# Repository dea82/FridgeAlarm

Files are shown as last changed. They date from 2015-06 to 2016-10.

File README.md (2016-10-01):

# FridgeAlarm

## System overview
Alarm system for unintentionally open fridge door

## Requirements

## Design
### Component selection

### Box design

### PCB

### Software
[Doxygen documentation](http://dea82.github.io/FridgeAlarm)

#### Doxygen deployment by Travis
The source code documentation is generated with [Doxygen](http://www.doxygen.com) and pushed automatically to GitHub Pages by [Travis CI](http://www.travis-ci.org).

##### Setup
This assumes that you've already figures out how to genereate Doxygen documentation and are able to build with Travis CI.

To be able to automatically update Doxygen documentation when a commit is done to GitHub follow these steps:
###### Generation of SSH-key
1. Generate a new SSH key with the following command: 
`ssh-keygen -t rsa -b 4096 -C "your_email@example.com"`
2. You are then prompted to enter a name for the new keypair. Enter a file in which to save the key.
3. When asked for passphrase just press ENTER for empty passphrase. Confirm with ENTER again.

###### Setup GitHub
1. Navigate to your GitHub settings page `https://github.com/<username>/<your_repository>/settings/keys` and paste the content from the public ssh-key file, the one ending with .pub. **Make sure to check the box that allows write access!**

###### Setup Travis CI
This is the trickiest part.
1. Make sure you're able to connect to Travis console.
2. Run command: `travis encrypt-file name-of-key-generated`.
It's the key that doesn't end with .pub that shall be used.
3. You get an instruction from Travis CI. As it says you should now make sure to add the returned key, ending with .enc, to your repository. All others keys can and should now be removed!
4. Next update your .travis.yml with the encryption label, the 12-digit hex value returned from step 2.
```
env:
	global:
    	- ENCRYPTION_LABEL: "12-digit hex value"
```
TODO: Finalize
https://gist.github.com/domenic/ec8b0fc8ab45f39403dd

## Verification

### Install
To upload the hex-file to the MCU (Attiny85) I use the following command with avrdude:
`avrdude -B250 -cusbasp -pt85 -Uflash:w:<path to hex file> -Ulfuse:w:0xE2:m -Uhfuse:w:0x55:m`
The -B250 makes it slow - however if the clock of the MCU is to slow it might not work otherwise.

#### Fuses
|MCU |Low fuse|High fuse|
|---|:---:|:---:|
|Attiny13A|0x7A |0xFA |
|Attiny85 |0xE2 |0x55 |
### Power consumption
The following current consumption has been observed with prototype pcb, Attiny85 and magnetic buzzer.
System mode      |Current consumption [mA]
-----------------|:-----------------------:
Buzzer and LED ON|42
LED ON			 |2.3
Deep sleep		 |0.024

The following current consumption has been observed with production pcb, Attiny13A and piezo buzzer.
System mode      |Current consumption [mA]
-----------------|:-----------------------:
Buzzer and LED ON|5
LED ON			 |2.2
Deep sleep		 |0.024

## Conclusion

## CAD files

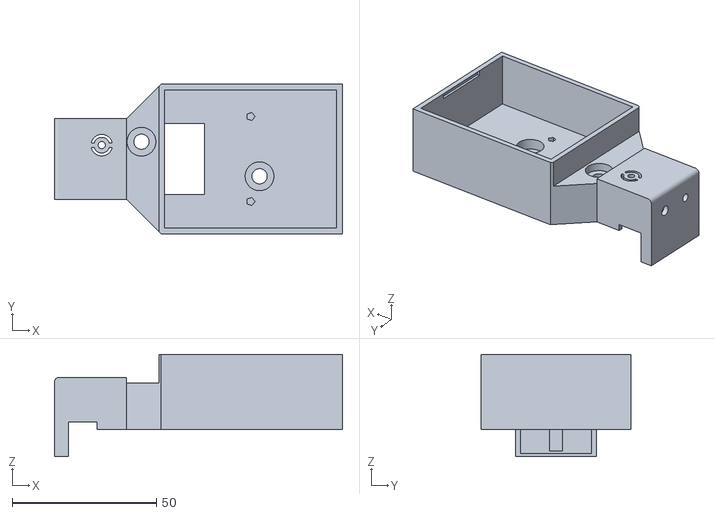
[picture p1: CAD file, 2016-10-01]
cad/production/main_case.stl
100.0 x 52.0 x 35.5

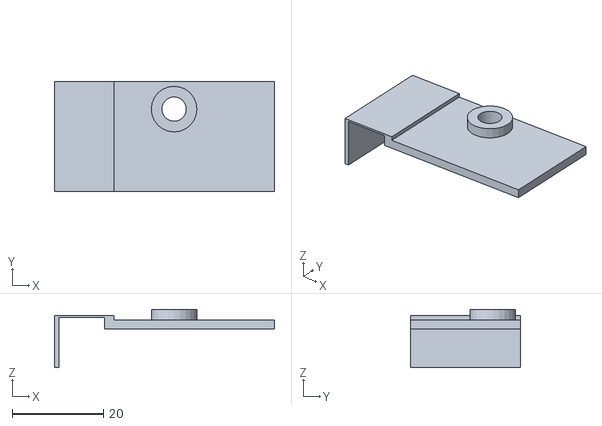
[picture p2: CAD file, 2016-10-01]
cad/production/pcb_lid.stl
48.2 x 24.0 x 12.8

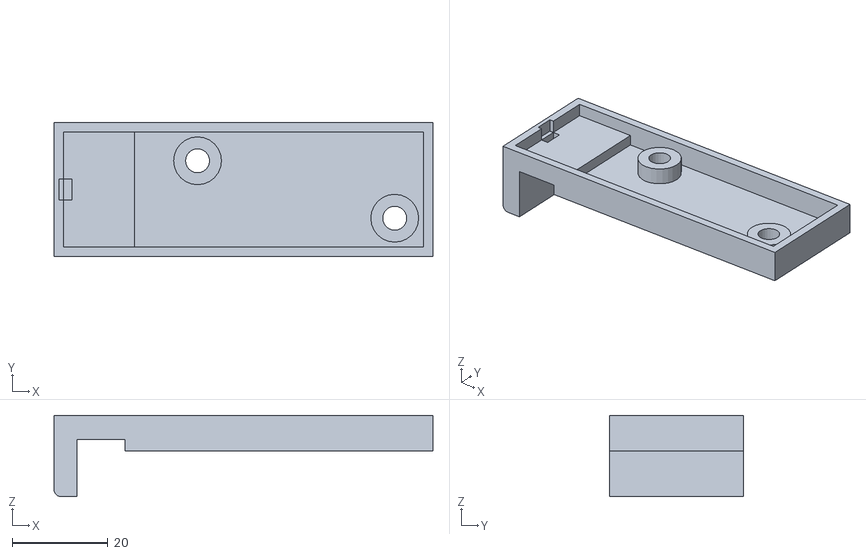
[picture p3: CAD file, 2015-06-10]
cad/prototype/case_bottom.stl
79.2 x 28.0 x 17.0

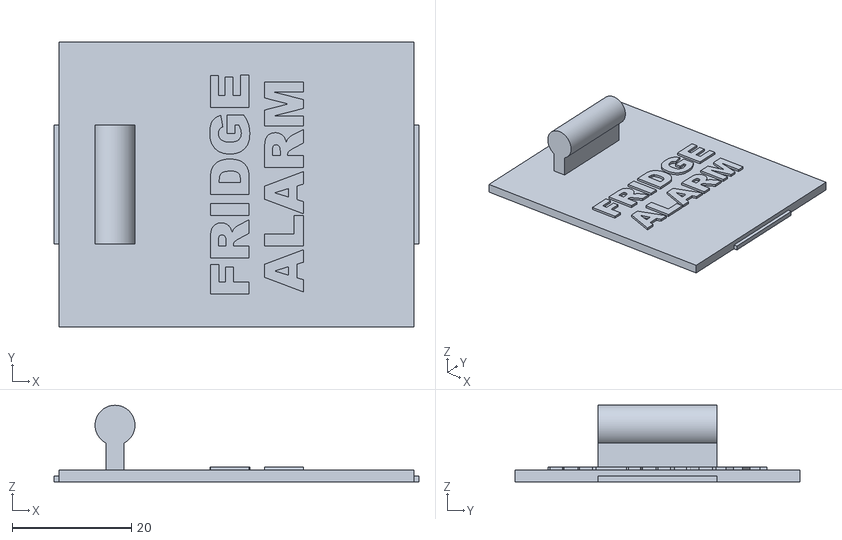
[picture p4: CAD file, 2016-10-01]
cad/production/battery_lid.stl
61.3 x 47.8 x 12.9

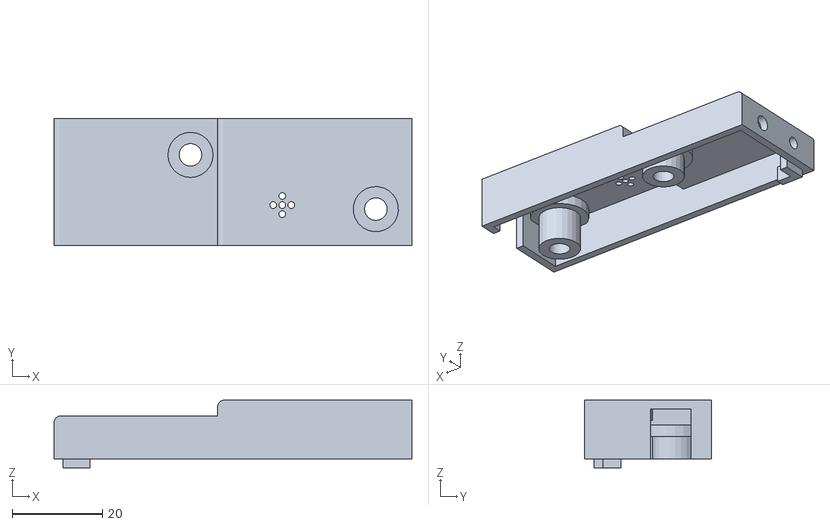
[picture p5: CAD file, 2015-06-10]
cad/prototype/case_top.stl
79.2 x 28.0 x 15.0

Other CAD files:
cad/production/assembly_production.skp
cad/prototype/assembly_prototype.skp

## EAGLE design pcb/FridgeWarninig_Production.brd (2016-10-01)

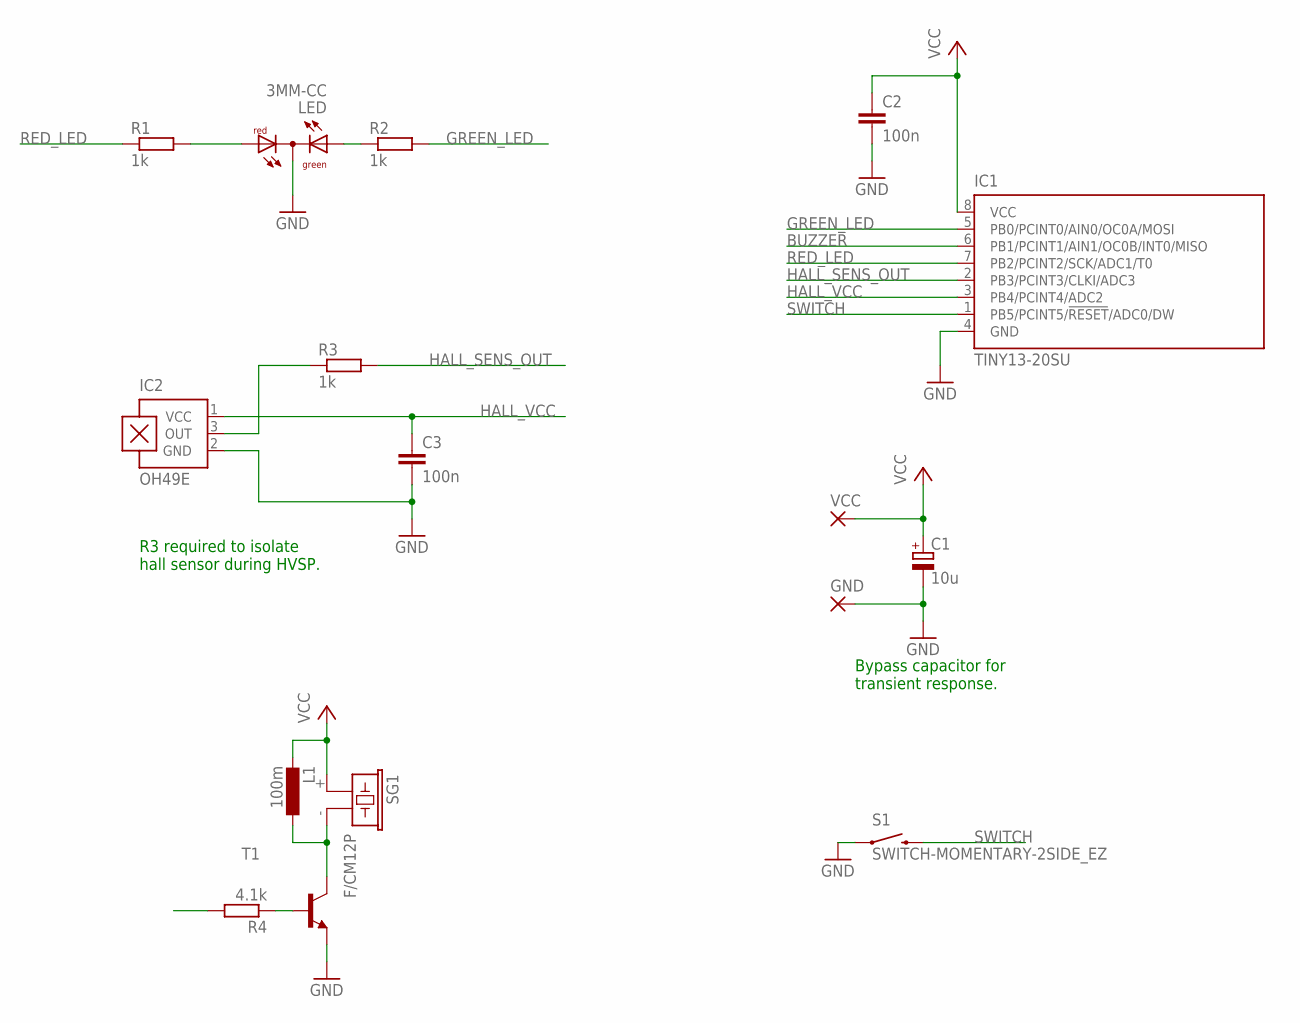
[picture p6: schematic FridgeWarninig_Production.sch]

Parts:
C1: 10u; 153CLV-0405
C2, C3: 100n; C0603
GND: 2,54/1,0
IC1: TINY13-20SU; 8S2
IC2: OH49E; SIP3-UA
L1: 100m; TT5D9L
LED: 3MM-CC; DUOLED-A-3MM
R1, R2, R3: 1k; R0603
R4: 4.1k; R0603
S1: SWITCH-MOMENTARY-2SIDE_EZ; TACTILE-PTH-SIDEEZ
SG1: F/CM12P
T1: MMBT918LT1-NPN-SOT23-BEC; SOT23-BEC
VCC: 2,54/1,0

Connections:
BUZZER: IC1.6 (PB1/PCINT1/AIN1/OC0B/INT0/MISO), R4.2
GND: C1.-, C2.2, C3.2, GND.1, IC1.4 (GND), IC2.2 (GND), LED.2 (C), S1.1, T1.E
GREEN_LED: IC1.5 (PB0/PCINT0/AIN0/OC0A/MOSI), R2.2
HALL_SENS_OUT: IC1.2 (PB3/PCINT3/CLKI/ADC3), R3.2
HALL_VCC: C3.1, IC1.3 (PB4/PCINT4/ADC2), IC2.1 (VCC)
unnamed: R4.1, T1.B
unnamed: L1.+ (1), SG1.- (2), T1.C
unnamed: IC2.3 (OUT), R3.1
unnamed: LED.1 (AG), R2.1
unnamed: LED.3 (AR), R1.2
RED_LED: IC1.7 (PB2/PCINT2/SCK/ADC1/T0), R1.1
SWITCH: IC1.1 (PB5/PCINT5/!RESET!/ADC0/DW), S1.2
VCC: C1.+, C2.1, IC1.8 (VCC), L1.- (2), SG1.+ (1), VCC.1

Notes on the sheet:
R3 required to isolate hall sensor during HVSP.
Bypass capacitor for transient response.

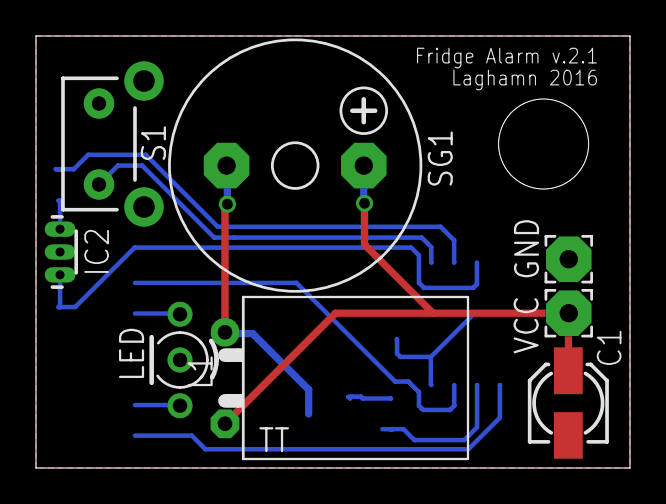
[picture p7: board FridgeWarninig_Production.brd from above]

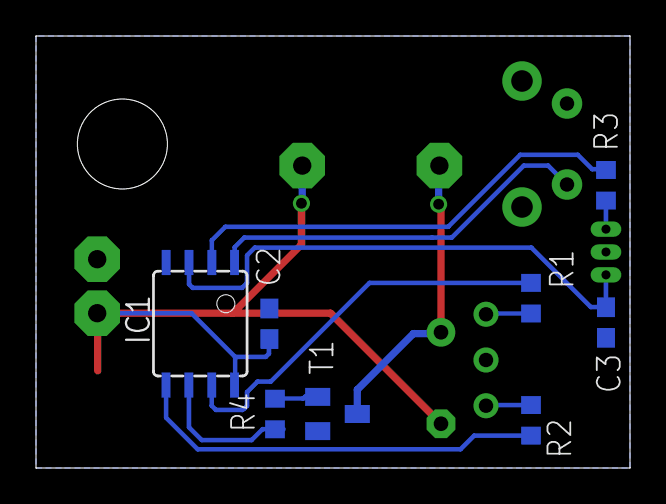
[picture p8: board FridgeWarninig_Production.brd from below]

Board: 2 copper layers, 33.0 x 24.0 mm, 16 parts (8 on the bottom side), 13 nets.

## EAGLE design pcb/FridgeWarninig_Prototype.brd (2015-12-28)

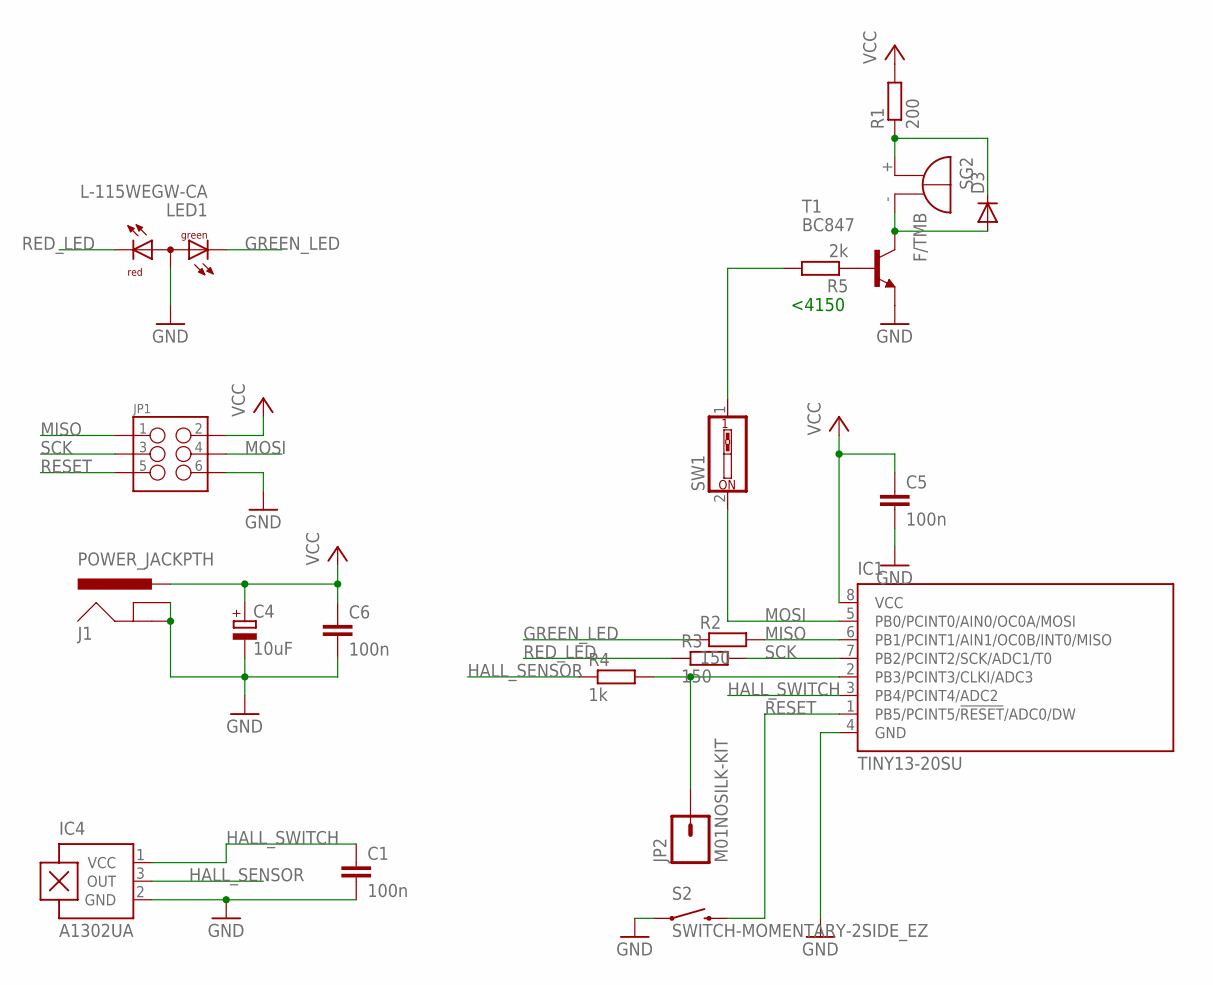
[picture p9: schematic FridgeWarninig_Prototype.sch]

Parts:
C1, C5, C6: 100n; C0603
C4: 10uF; E2-5
D3: DIODE-DO-214AC; DO-214AC
IC1: TINY13-20SU; 8S2
IC4: A1302UA; SIP3-UA
J1: POWER_JACKPTH; POWER_JACK_PTH
JP1: M03X2SHROUD; 2X3-SHROUDED
JP2: M01NOSILK-KIT; 1X01NS-KIT
LED1: L-115WEGW-CA; DUOLED-A-3MM
R1: 200; R0603
R2, R3: 150; R0603
R4: 1k; R0603
R5: 2k; R0603
S2: SWITCH-MOMENTARY-2SIDE_EZ; TACTILE-PTH-SIDEEZ
SG2: F/TMB
SW1: SW_DIP-1; EDG-01
T1: BC847; SOT23

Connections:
GND: C1.2, C4.-, C5.2, C6.2, IC1.4 (GND), IC4.2 (GND), J1.GND, J1.GNDBREAK, JP1.6, LED1.2 (A), S2.1, T1.2 (E)
GREEN_LED: LED1.1 (CG), R2.1
HALL_SENSOR: IC4.3 (OUT), R4.1
HALL_SWITCH: C1.1, IC1.3 (PB4/PCINT4/ADC2), IC4.1 (VCC)
MISO: IC1.6 (PB1/PCINT1/AIN1/OC0B/INT0/MISO), JP1.1, R2.2
MOSI: IC1.5 (PB0/PCINT0/AIN0/OC0A/MOSI), JP1.4, SW1.2
unnamed: R5.2, SW1.1
unnamed: D3.2 (A), SG2.-, T1.3 (C)
unnamed: IC1.2 (PB3/PCINT3/CLKI/ADC3), JP2.1, R4.2
unnamed: D3.1 (C), R1.1, SG2.+
unnamed: R5.1, T1.1 (B)
RED_LED: LED1.3 (CR), R3.1
RESET: IC1.1 (PB5/PCINT5/!RESET!/ADC0/DW), JP1.5, S2.2
SCK: IC1.7 (PB2/PCINT2/SCK/ADC1/T0), JP1.3, R3.2
VCC: C4.+, C5.1, C6.1, IC1.8 (VCC), J1.PWR, JP1.2, R1.2

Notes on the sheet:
<4150

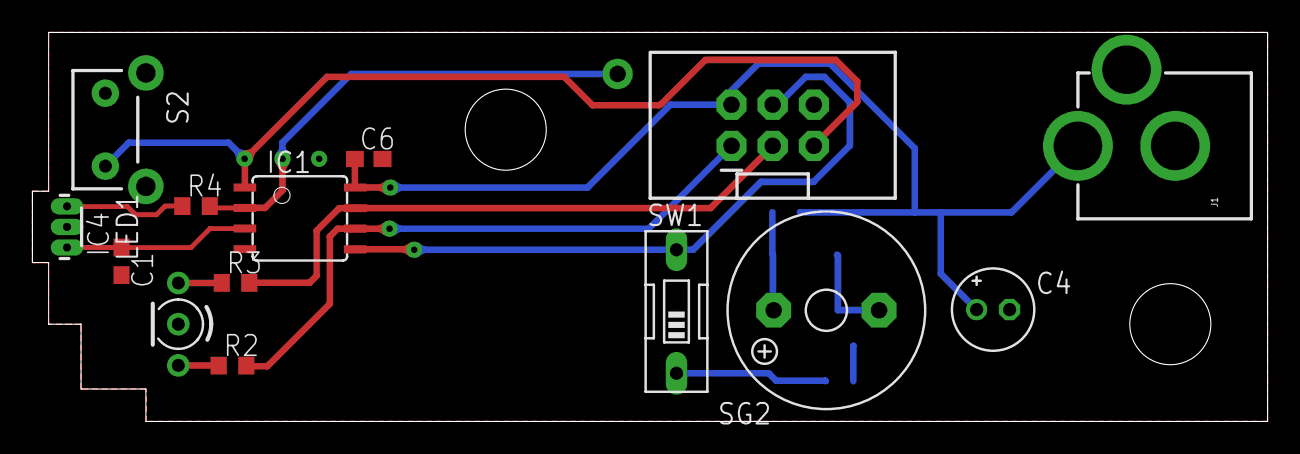
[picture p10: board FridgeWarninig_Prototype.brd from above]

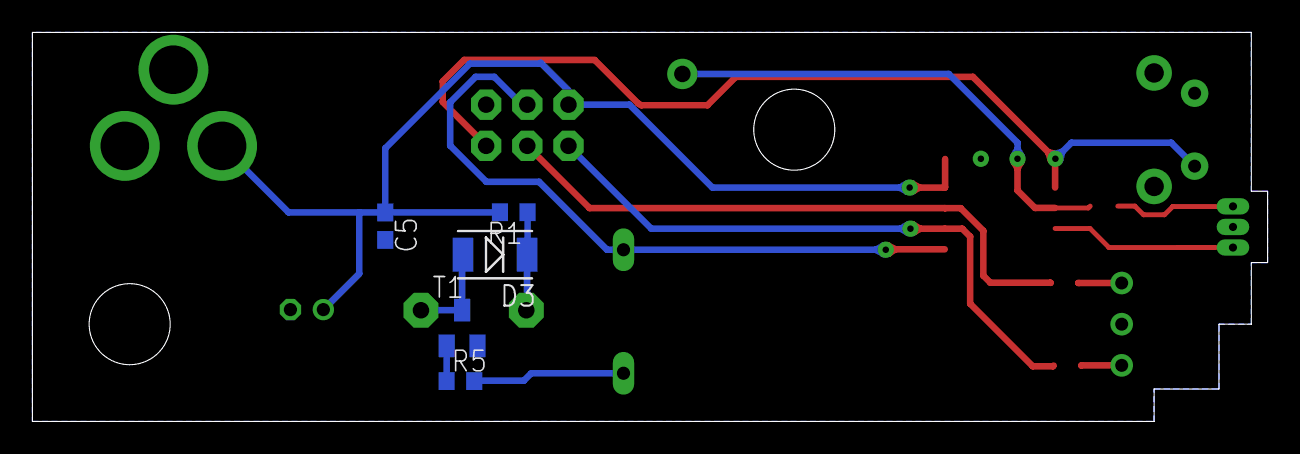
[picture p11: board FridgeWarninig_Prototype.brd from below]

Board: 2 copper layers, 76.2 x 24.0 mm, 20 parts (5 on the bottom side), 15 nets.

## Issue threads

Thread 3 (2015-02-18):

Setup fuse bits

dea82, 2015-02-18:
Setup the fuse bits and export to file. Internal 128kHz clock shall be used and no brown-out.

dea82, 2015-05-31:
BOD shall be used and "lowest possible" clock speed.

dea82, 2015-12-17:
BOD is now enabled. Highest possible clock speed is used, then more sleep time will be achived and in total better power consumption.

Closed 2015-12-17.

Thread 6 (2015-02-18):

Create Door SWitch Controller

dea82, 2015-02-18:
Create dswc module with the following functions.
Dswc_init - initialize inputs
Dswc_loop - get switch states
calcDoorSwitchState - converts input to enumerated value with filtering of 1 s.
Dswc_getDoorState - gets door state Opened/Closed with signal status.

dea82, 2015-05-25:
Door switch will not be used in this project any more.

Closed 2015-05-25.

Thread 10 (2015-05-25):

Decide CPU clock

dea82, 2015-05-25:
Decide which clock speed shall be used and what prescaler.

dea82, 2015-06-04:
4.8 MHz with divided with 8 by fuse can be used.

dea82, 2015-11-10:
Easiest way of doing this is to try different clock speed. Create an extra define variable to activate an algorithm that can measure clock cycle and pass it out over uart.

dea82, 2015-12-09:
Do #35 and answer is clear.

dea82, 2015-12-16:
Due to that a higher clock speed gives shorter time awake and longer time at sleep that will be most efficient.

dea82, 2015-12-17:
Changed to fastest clock speed available to maximize sleep time. 8 Mhz internal RC.

Closed 2015-12-17.

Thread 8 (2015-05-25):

Setup ADC conversion for hall effect sensor

dea82, 2015-05-25:
Setup ADC conversion for hall effect sensor.

- Choose a suitable prescaler and make sure that error message is printed if F_CPU is changed.
- Single conversion shall be used.
- Turn of ADC when not used.
- Don't use interrupt trigger when ADC is completed. Wait for it instead, because it will make clearer code at first. Priority is small code.

Closed 2015-06-01.

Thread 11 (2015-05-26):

Advantage of switch connected to INT0

dea82, 2015-05-26:
Are there any advantage letting the switch be connected to INT0. Wake-up? Lower clock speed?

dea82, 2015-05-27:
All pins can have pin change interrupt. The only disadvantage of PCINT compared to INT0 is that you have to find out which of the PCINT causing the interrupt. So it will take a couple of bytes extra flash. Both PCINT and INT0 can be used to wake-up the MCU from power-down. However if the MCU shall be possible to put into power-down the WatchDog must be used to wake-up the MCU to read door sensor. New issue to find out consequences of using watch dog at power down.

dea82, 2015-05-27:
If only one PCINT interrupt is enabled it shouldn't be nessecary to find out who caused the interrupt.

Closed 2015-05-27.

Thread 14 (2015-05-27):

Watchdog

dea82, 2015-05-27:
What will the consequences be of using the watchdog for wakeup from power-down? Current consumption? Better to stay in Idle? Disable it when normal operation?

dea82, 2015-05-30:
Power down shall be used.
Idle has a current consumption >0.5 mA @ 4.8 MHz.
Power down has a curren consumption <0.7 uA with watchdog timer enabled.

Closed 2015-05-30.

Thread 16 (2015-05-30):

Cause of reset

dea82, 2015-05-30:
Is there a need to find out what caused reset? Watchdog? BOD? Etc...

dea82, 2015-05-30:
During development it can give indication of problems with power supply or resources. Start simple and if a BOD-reset or WDT reset is triggered lock into failure mode.

dea82, 2015-06-03:
No room for this on the Attiny13a platform.

Closed 2015-06-03.

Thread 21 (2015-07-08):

Improvement on PCB

dea82, 2015-07-08:
[X] Add bypass capacitor at hall sensor
[X] Add electrolyt capacitor at output pin on voltage regulator, verify it fits!
[X] Change pin distance on buzzer
[X] Add transistor to drive buzzer, and add diode.
[N] Add transistor to drive LED?
[X] Add switch to buzzer
[N] Add pot to buzzer?
[X] Prepare reset pin for usage as output (remove diode!)
[ ] Verify pin distance of button, should be 4.5 mm.
[ ] Possible to shrink footprint of hall sensor?
[ ] Investigate why buzzer makes sound at sleep.
[X] Any chance to disconnect hall-sensor from 5V supply?

Closed 2015-07-21.

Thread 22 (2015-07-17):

Activate pull-up when hall sensor is not read?

dea82, 2015-07-17:
Activate pull-up on the pin connected to the hall sensor. This will minimize the current consumption?

dea82, 2015-12-18:
Find out if it's "floating" when sensor is not powered or if it's considered connected to ground.

dea82, 2016-05-13:
Tried to activate pull-up and power consumption increased with 70 uA, so that was a bad idea. Also tried to make it an output without change in consumption.

Closed 2016-05-13.

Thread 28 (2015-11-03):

Build flag uart

dea82, 2015-11-03:
Create a buildflag to enable build of uart function. Default pin function will be replaced depending ön this buildflag.

dea82, 2015-12-08:
Duplicate

Closed 2015-12-08.

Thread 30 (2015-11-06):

Create assembly file

dea82, 2015-11-06:
Create assembly file for uart, uart.S.
This shall contain at least:
- Interrupt routine for Timer0, verify it's reached.

Closed 2015-12-08.

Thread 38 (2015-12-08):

Create macro that prints (info) expected error % for uart

dea82, 2015-12-08:
Create macro that prints (info) expected error % for uart.

dea82, 2015-12-18:
Do it separate in documentation.

dea82, 2016-04-12:
Possible to do with a combination of makefile and shell script see:
https://github.com/Optiboot/optiboot/tree/master/optiboot/bootloaders/optiboot (file baudcheck.c)

Closed 2016-09-30.

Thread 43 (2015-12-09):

Change compiler option

dea82, 2015-12-09:
Linker Relaxation
    -Wl,--relax
    Almost always a win. Note that this is a linker flag that is passed to the linker using the -Wl flag.
    Enables linker relaxations. By default, the linker links functions will a full CALL statement, which is wasteful if two functions are near each other. Relaxations will do more in the future, but currently (AFAIK) just replace CALL statements with RCALL where possible to save a few bytes.

Closed 2015-12-11.

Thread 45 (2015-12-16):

Brown-Out detection

dea82, 2015-12-16:
Activate BOD at 2.7V level. Make sure to change level to 2.7V. Also set startup time to lowest possible SUT[1:0] = 00
Implement a function that detects if a BOD-reset has occured, then shall the led be flashing red instead and BOD shall be software disabled all the time?

dea82, 2015-12-16:
Not possible to disable BOD, only during sleep.

Closed 2015-12-17.

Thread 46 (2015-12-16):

Button should be tied to pull-up

dea82, 2015-12-16:
Button should be tied to pull-up otherwise it's floating and consuming current due to the input buffer is still enabled due to the enabled external interrupt.

Closed 2015-12-17.

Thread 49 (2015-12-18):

Noisy buzzer

dea82, 2015-12-18:
The buzzer sounds noisy due to the adc sleep mode. When buzzer is active go to idle instead. Rewrite power down function.

Closed 2015-12-23.

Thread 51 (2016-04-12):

Power estimation

dea82, 2016-04-12:
Make a power estimation, preferably an excel sheet.

dea82, 2016-05-13:
Attiny85: It's not possible to activate BOD software disable. Power consumption is:
During deep sleep: 24uA
LED on no buzzer 2300 uA
Buzzer on and with led: 52 mA

dea82, 2016-06-16:
Verify that attiny13A can be enable BOD sleep during power down.

dea82, 2016-08-25:
With piezo buzzer instead of magnetic buzzer it drops dramativally. Tested on BB and it piezo current draw is down to about 2.5 mA (only for piezo), simplified it went from ~50 mA => 2.5 mA.

dea82, 2016-10-01:
Unable to put Attiny13A into sleep with BOD deactivated for some reason. Inspected assembly code which seems correct.

Closed 2016-10-01.

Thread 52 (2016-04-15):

Improve cpu load module with overflow check

dea82, 2016-04-15:
By checking TIFR - TOV0 bit the function for checking the cpu load can be improved. If this has been set the prescaler should be increased by the user (automatic?) to a higher value. The user should be informed through uart about this.

dea82, 2016-04-15:
Updated and check overflow, not automatic.

dea82, 2016-05-17:
The module assembly file shall be as small as possible (small flash req). Automatic prescaler can then be implemented at higher level.

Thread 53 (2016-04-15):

Add possibility fo a generic pin uart output

dea82, 2016-04-15:
Improve Uart_transmit function to take a generic pin as input and output byte on that pin.

dea82, 2016-05-24:
Pin is defined both in uart.c and uart_asm.S now. At least define it once.

dea82, 2016-07-10:
It's now defined in conf.h. Verify proper function.

dea82, 2016-09-14:
Uart verified working!

Closed 2016-09-14.

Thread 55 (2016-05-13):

Don't leave buzzer pin in high state

dea82, 2016-05-13:
The pin to the buzzer is froozen when timer is stopped. It actually can be left high! Not good for current consumption.

dea82, 2016-05-13:
Fixed!

Closed 2016-05-13.

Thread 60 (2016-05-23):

Add MCU type, UART and CPUL to makefile

dea82, 2016-05-23:
Move these to makefile. This will make it possible to build for multiple targets and configurations on Travis.

dea82, 2016-05-24:
Check comment in issue #38.

Closed 2016-06-15.

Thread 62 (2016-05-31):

Compensate for supply voltage to hall sensor

dea82, 2016-05-31:
The hall sensor is not supplied with same voltage as ADC. It's slightly less about 0,135 V. It corresponds to a ADC range from 0 - 986, instead of 0 - 1024. Mid value should be 493, verify with measurement on circuit. Should it be compensated for natural magnetic field?

dea82, 2016-05-31:
Measured value 496, very close! Measurement done at a slightly higher battery voltage (lower output voltage loss) than 3.6V so it seems very accurate!

Closed 2016-06-16.

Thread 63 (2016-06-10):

Documentation in Doxygen

dea82, 2016-06-10:
Document the project with help of Doxygen. Make a md file which can be used on github and included in the Doxygen docs. It shall describe some of the design choices made, components selected, PCB design, case design, calculations made and measurements on final system. Instructions to build, upload etc should also be included. Pictures, illustrations and drawings shall be attached if necessary.

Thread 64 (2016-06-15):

Wrong CPU load estimation

dea82, 2016-06-15:
The CPU load estimation incorrect. The buzz module is completly outcommented, and is not included in the cpu load.
Change the uart output to take control over buzzer pin only when doing any output and release the pin back to the buzzer afterwards. Then make sure buzzer is run.

dea82, 2016-09-30:
Changed to use UART on led pin instead.

Closed 2016-09-30.

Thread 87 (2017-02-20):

Restructure build targets

dea82, 2017-02-20:
Restructure folders:
common
targets/production
targets/prototype

Restructure Cmake file to adapt this more correct way. Is it possible to build common once for both targets? Probably not...?

dea82, 2017-02-21:
Remember it's possible to forward declare a function and move function to another file without declaring it in a header. Like dispatchTask in main.c.

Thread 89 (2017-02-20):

Replace crc8 with avrlibc

dea82, 2017-02-20:
With docker avrlibc will be of a known version, switch to use the built in function in avrlibc.

Closed 2017-02-26.

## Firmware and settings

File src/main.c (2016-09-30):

/*
The MIT License (MIT)

Copyright (c) 2015-2016 Andreas L.

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
THE SOFTWARE IS PROVIDED "AS IS", WITHOUT WARRANTY OF ANY KIND, EXPRESS OR
IMPLIED, INCLUDING BUT NOT LIMITED TO THE WARRANTIES OF MERCHANTABILITY,
FITNESS FOR A PARTICULAR PURPOSE AND NONINFRINGEMENT. IN NO EVENT SHALL THE
AUTHORS OR COPYRIGHT HOLDERS BE LIABLE FOR ANY CLAIM, DAMAGES OR OTHER
LIABILITY, WHETHER IN AN ACTION OF CONTRACT, TORT OR OTHERWISE, ARISING FROM,
OUT OF OR IN CONNECTION WITH THE SOFTWARE OR THE USE OR OTHER DEALINGS IN
THE SOFTWARE.
*/

/**
 * @file
 */

/*** User library ***/
#include "butt.h"
#include "buzz.h"
#include "conf.h"
#include "cont.h"
#include "door.h"
#include "ledc.h"
#include "pwrd.h"
#include "type.h"
#if WCET
#include <avr/pgmspace.h>
#include "wcet.h"
#endif

/* Macro for putting string in flash during WCET measurement. */
#if WCET
#define PSTR_WCET(STRING) PSTR(STRING)
#else
#define PSTR_WCET(STRING) STRING
#endif

/* Macro for declaring parameter as unused during WCET measurement. */
#if WCET
#define UNUSED_WITHOUT_WCET(param) param
#else
#define UNUSED_WITHOUT_WCET(param) UNUSED(param)
#endif

static void dispatchTask(const char * UNUSED_WITHOUT_WCET(taskName_c),
                         void (* const task_fptr)(void),
                         const tU08 UNUSED_WITHOUT_WCET(prescaler_U08));

/**
 * [addTask description]
 * @param taskName_c [description]
 * @param task_fptr  [description]
 */
static void dispatchTask(const char * UNUSED_WITHOUT_WCET(taskName_c),
                         void (* const task_fptr)(void),
                         const tU08 UNUSED_WITHOUT_WCET(prescaler_U08))
{
#if WCET
    Wcet_StartMeasurement(prescaler_U08);
#endif
    task_fptr();
#if WCET
    Wcet_StopMeasurement();
    Wcet_OutputResult(taskName_c, prescaler_U08);
#endif
}

/* Declaring main as OS_main saves some register pushing to stack. */
__attribute__((OS_main)) int main(void)
{
    /* ATTENTION! Initialization code can be found in boot.S */

    /* Check for WDT reset (save code size and assume true) - if a runaway pointer enables it,
     * then it must be disabled here because it's kept after a reset! Ref. AVR132 chap 2.4.
     * Reset status register because it will cause a new WDT reset if WDRF is set. Make sure
     * to save it for later useage to detect if abnormal reset has occured.
     */
    {
        tU08 statusRegister_U08 = MCUSR;
        MCUSR = 0;
        WDTCR = _BV(WDCE) | _BV(WDE);
        WDTCR = 0;

        /* Power saving - switch of analog comparator */
        ACSR |= _BV(ACD);

        /* Initialize I/O Ports */
        DDRB = DDRB_INIT;
        PORTB |= PORTB_INIT; /* Optimization, only one bit is changed */

        /* Initialize sensors */
        Butt_Init();
        Door_Init();
        /* Initialize controls */
        Cont_Init();
        /* Initialize actuators */
        Buzz_Init();
        Ledc_Init();

        /* Enable global interrupt otherwise door will not be able to wake up
         * from ADC Noise reduction mode or infinite sleep mode. */
        asm volatile("sei"::);

        /**
         * Abnormal reset detected - goto infinite sleep with orange led
         * indicating that we have a system error. Put the MCU in "infinite"
         * sleep to save power, it could be BOD reset due to low batteries.
         * The MCU is however possible to wakeup with the button - then it
         * will go back to normal function.
         */
        if(!(statusRegister_U08 & _BV(PORF)))
        {
            Butt_EnableInterrupt();
            Ledc_SetOrange();
            Pwrd_SetSleepMode(PWRD_INFINITE_SLEEP_E);
            Pwrd_Sleep();
        }
    }

    for (;;)
    {

        /* Startup */
        Pwrd_Wakeup();

        /* Sensors */
        dispatchTask(PSTR_WCET("BUTT"), Butt_Loop, 1);
        dispatchTask(PSTR_WCET("DOOR"), Door_Loop, 1);

        /* Controls */
        dispatchTask(PSTR_WCET("CONT"), Cont_Loop, 1);

        /* Actuators */
        dispatchTask(PSTR_WCET("BUZZ"), Buzz_Loop, 1);
        dispatchTask(PSTR_WCET("LEDC"), Ledc_Loop, 1);

        /* Powerdown */
        Pwrd_Sleep();
    }

    return 0;
}

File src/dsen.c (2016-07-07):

/*
The MIT License (MIT)

Copyright (c) 2015-2016 Andreas L.

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
THE SOFTWARE IS PROVIDED "AS IS", WITHOUT WARRANTY OF ANY KIND, EXPRESS OR
IMPLIED, INCLUDING BUT NOT LIMITED TO THE WARRANTIES OF MERCHANTABILITY,
FITNESS FOR A PARTICULAR PURPOSE AND NONINFRINGEMENT. IN NO EVENT SHALL THE
AUTHORS OR COPYRIGHT HOLDERS BE LIABLE FOR ANY CLAIM, DAMAGES OR OTHER
LIABILITY, WHETHER IN AN ACTION OF CONTRACT, TORT OR OTHERWISE, ARISING FROM,
OUT OF OR IN CONNECTION WITH THE SOFTWARE OR THE USE OR OTHER DEALINGS IN
THE SOFTWARE.
*/

/**
 * @file
 */

#include "dsen.h"

#include <avr/interrupt.h>
#include <avr/io.h>
#include <util/delay.h>

#include "conf.h"

/** 
 * Due to ~0.135 V supply loss to sensor compared with supply to ADC-converter 
 * the normal ADC-range will be 0-986 instead of 0-1023.
 */
#define UNAFFECTED_SENSOR_VALUE 493
/* Offset from stored position to trigger alarm. [-]*/
#define DOOR_CLOSED_OFFSET 20
/* Minimum accepted door position (calculated offset from 512) [-] */
#define MIN_CAL_DOOR_CLOSED_POS 60

static tDsen_doorState_str doorState_str;
static tU16 doorClosed_U16;
static tU16 doorPos_U16;

static tB withinRange_B(const tU16 sensorValue_U16);
static tU16 getDoorRawPos_U16(void);
static void eepromWrite(const tU08 address_U08, const tU08 data_U08);
static tU08 eepromRead_U08(const tU08 address);

/**
 * @brief Setup ADC conversion.
 */
inline void Dsen_init(void)
{
#if F_CPU == 9600000
    /* Prescaler for ADC clock is set to 64, which gives a ADC clock of 150 kHz. */
    ADCSRA = (1 << ADPS2) | (1 << ADPS1);
#elif F_CPU == 1000000
    /* Prescaler for ADC clock is set to 8, which gives a ADC clock of 125 kHz. */
    ADCSRA = (1 << ADPS1) | (1 << ADPS0);
#elif F_CPU == 1200000
    /* Prescaler for ADC clock is set to 8, which gives a ADC clock of 150 kHz. */
    ADCSRA = (1 << ADPS1) | (1 << ADPS0);
#elif F_CPU == 4800000
    /* Prescaler for ADC clock is set to 32, which gives a ADC clock of 150 kHz. */
    ADCSRA = (1 << ADPS2) | (1 << ADPS0);
#elif F_CPU == 600000
    /* Prescaler for ADC clock is set to 4, which gives a ADC clock of 150 kHz. */
    ADCSRA = (1 << ADPS1);
#elif F_CPU == 8000000
    /* Prescaler for ADC clock is set to 64, which gives a ADC clock of 125 kHz. */
    ADCSRA = (1 << ADPS2) | (1 << ADPS1);
#else
#error "Prescaler for ADC conversion is not supported for this CPU clock."
#endif

    /* Connect pin to ADC with 10-bit precision */
    ADMUX = (_BV(MUX1) | _BV(MUX0));

    doorClosed_U16 = (eepromRead_U08(0) << 8);
    doorClosed_U16 += eepromRead_U08(1);
}

inline void Dsen_loop(void)
{
    doorPos_U16 = getDoorRawPos_U16();

    tDsen_doorState_E newDoorState_E;
    /* Algorithm handles both direction of magnet field */
    if (doorClosed_U16 < UNAFFECTED_SENSOR_VALUE)
    {
        if (doorPos_U16 > doorClosed_U16 + DOOR_CLOSED_OFFSET)
        {
            newDoorState_E = DSEN_OPEN_E;
        }
        else
        {
            newDoorState_E = DSEN_CLOSED_E;
        }
    }
    else
    {
        if (doorPos_U16 < doorClosed_U16 - DOOR_CLOSED_OFFSET)
        {
            newDoorState_E = DSEN_OPEN_E;
        }
        else
        {
            newDoorState_E = DSEN_CLOSED_E;
        }
    }

    if (doorState_str.doorState_E == newDoorState_E)
    {
        INC_U16(doorState_str.ticksInState_U16);
    }
    else
    {
        doorState_str.ticksInState_U16 = 0;
    }
    doorState_str.doorState_E = newDoorState_E;

}

/**
 * Make an AD conversion
 * @return  door position
 */
static tU16 getDoorRawPos_U16(void)
{
    tU16 sensorValue_U16;


    /* Prepare for sleep - check if timer is running.
     * Assume that timer is not running if module is disconnected. */
    if (PRR & _BV(PRTIM0))
    {
        /* Sleep mode ADC noise reduction */
        MCUCR = _BV(SE) | _BV(SM0);
    }
    else
    {
        /* Sleep mode idle */
        MCUCR = _BV(SE);
    }

    /* Turn on sensor */
    IO_SET(DSEN_SWITCH_CFG);

    /* Activate ADC module */
    PRR &= ~_BV(PRADC);

    /* According to (Allegro 1302) data sheet of sensor star-up time is 5 us.*/
    _delay_us(5);

    /* Clear any pending interrupt - should not happen */
    ADCSRA |= _BV(ADIF);
    /* Start conversion */
    ADCSRA |= _BV(ADEN) | _BV(ADSC) | _BV(ADIE);

    /* Necessary check if any other interrupt wakes the MCU. */
    while (ADCSRA & _BV(ADSC))
    {
        /* Wait for conversion */
        asm volatile("sleep"::);
    }

    /* Disable interrupt and ADC. */
    ADCSRA &= ~(_BV(ADEN) | _BV(ADIE));

    /* Turn off sensor */
    IO_CLR(DSEN_SWITCH_CFG);

    /* Power savings */
    PRR |= _BV(PRADC);

    sensorValue_U16 = ADCL;
    sensorValue_U16 |= ((ADCH & 0x3) << 8);

    return sensorValue_U16;
}

tDsen_doorState_str Dsen_getDoorState_str(void)
{
    return doorState_str;
}

static tB withinRange_B(const tU16 sensorValue_U16)
{
    tB ret_B = FALSE;
    /* Cast should not be a problem due to the 10-bit resolution. */
    if (ABS((tS16)sensorValue_U16 - UNAFFECTED_SENSOR_VALUE) > MIN_CAL_DOOR_CLOSED_POS)
    {
        ret_B = TRUE;
    }
    else
    {
        ret_B = FALSE;
    }

    return ret_B;
}

tB Dsen_storeClosedPos_B(void)
{
    tB calibrationOk_B = FALSE;
    if (withinRange_B(doorPos_U16))
    {
        eepromWrite(0x00, HI(doorPos_U16));
        eepromWrite(0x01, LO(doorPos_U16));
        doorClosed_U16 = doorPos_U16;
        calibrationOk_B = TRUE;
    }
    return calibrationOk_B;
}


static void eepromWrite(const tU08 address_U08, const tU08 data_U08)
{
    /* Wait for completion of previous write */
    while(EECR & _BV(EEPE));
    /* Set Programming mode */
    EECR = 0;
    /* Set up address and data registers */
    EEAR = address_U08;
    EEDR = data_U08;
    /* Timed sequence - disable interrupt */
    cli();
    /* Write logical one to EEMPE */
    EECR |= (1<<EEMPE);
    /* Start eeprom write by setting EEPE */
    EECR |= (1<<EEPE);
    sei();
}

static tU08 eepromRead_U08(const tU08 address_U08)
{
    /* Wait for completion of previous write */
    while(EECR & (1<<EEPE));
    /* Set up address register */
    EEAR = address_U08;
    /* Start eeprom read by writing EERE */
    EECR |= (1<<EERE);
    /* Return data from data register */
    return EEDR;
}

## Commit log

2015-02-19 Upload PCB:s. Closes #4.
    [FridgeWarninig_0.1.brd, FridgeWarninig_0.1.sch]
2015-02-22 Updated PCB and added printable pdf.
    [FridgeWarninig_0.1.brd]
2015-02-28 Added a lot of new preliminary code: - Buzzer control - Led control - Scheduler - Switch monitor - New version of PCB - Configuration file
    [DRILEGEND.CFG]
2015-02-28 Update led control.
2015-04-25 Added cad files and a lot others. Update before formatting local disk.
    [Case.obj, Case.skp, Case.stl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]
2015-05-30 A lot of changes no specific issue.
    [conf.h, main.c]
2015-05-31 13: CPU load - implement
    Task-Url: http://github.com/dea82/FridgeAlarm/issues/issue/13
    [conf.h, main.c]
2015-05-31 18: Implement simple way to indicate lockmode
    Task-Url: http://github.com/dea82/FridgeAlarm/issues/issue/18
    [conf.h, ledc.c, main.c]
2015-05-31 9: Create macros for IO control
    Task-Url: http://github.com/dea82/FridgeAlarm/issues/issue/9
    Close #9.
    [conf.h]
2015-06-01 17: Enable PCINT interrupt
    Task-Url: http://github.com/dea82/FridgeAlarm/issues/issue/17
    Close #17.
    [main.c]
2015-06-01 Moved button interrupt en/disable to butt.
2015-06-01 8: Setup ADC conversion for hall effect sensor
    Task-Url: http://github.com/dea82/FridgeAlarm/issues/issue/8
    Close #8.
    [conf.h, main.c]
2015-06-01 Missed a lot of new files.
    [cont.c, dsen.c]
2015-06-03 Prototype code, everything seems to work at the moment. The code shall be cleaned and this is a less function version for Attiny13A. Simplified calibration etc.
    Close #5
2015-06-05 Big update on CAD drawing. Upper lid created.
    [Case_hall_sensor_0.2.skp]
2015-06-09 Updated CAD-drawings. Only holes for speaker missing.
    [Case_hall_sensor.skp]
2015-06-09 Removed some old files.
    [Case.skp, Case.stl, Case_hall_sensor_0.2.skp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]
2015-06-09 Added holes for speaker.
    [Case_hall_sensor.skp]
2015-06-09 New version of PCB.
    [FridgeWarninig_0.5.brd, FridgeWarninig_0.5.sch]
2015-06-10 Made a huge clean of unnecessary files.
    [Case.obj, Case_bottom.stl, Case_top.stl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]
2015-06-24 Optimized code. Final CAD-model of case.
    [Case_hall_sensor.skp, FridgeWarninig_0.5.brd, FridgeWarninig_0.5.sch]
2015-06-24 Added door state partially open which will enable a shorter alarm time for a door which seems closed but isn't.
    [conf.h, cont.c, dsen.c]
2015-06-25 Revert "Added door state partially open which will enable a shorter alarm time for a door which seems closed but isn't."
    This reverts commit 34d5dfc61c6f11f07fcf84b0bc87ceb58ea36388.
    [conf.h, cont.c, dsen.c]
2015-07-06 Made some small fixes: - Connect correct pins in conf.h. - Fix interrupt handling of button. - Small function improvement. - Small power improvement.
    [conf.h, cont.c, dsen.c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]
2015-07-07 19: Watchdog interrupt can freeze MCU
    Task-Url: http://github.com/dea82/FridgeAlarm/issues/issue/19
    [main.c]
2015-07-07 Fixed buzzer sound. Does not work on batteries.
    [conf.h, cont.c, main.c]
2015-07-20 Added transistor to supply hall-sensor.
    [FridgeWarninig_0.5.brd, FridgeWarninig_0.5.sch]
2015-07-21 Close #21. Made several small improvements on the PCB design to better fit battery supply.
    [FridgeWarninig_0.5.brd, FridgeWarninig_0.5.sch]
2015-08-18 Preparation for new battery powered pcb design.
2015-10-26 Updates after converting to battery power supply.
    [FridgeWarninig_0.5.brd, FridgeWarninig_0.5.sch]
2015-11-01 Updated power reduction.
2015-11-02 26: Create uart-files
    Task-Url: http://github.com/dea82/FridgeAlarm/issues/issue/26
    [conf.h, uart.c]
2015-11-05 #Close 29: Uart transmit
    Task-Url: http://github.com/dea82/FridgeAlarm/issues/issue/29
    [dsen.c, main.c, uart.c]
2015-11-06 Update uart.c
    Made a correction of counter when sending a byte just after another.
    [uart.c]
2015-12-01 Rewrite the uart into assembler.
2015-12-02 Update uart_asm.S
    Removed unnecessary set carry instruction
    It's not necessary to set the carry flag due to the fact that instuction, com, does that already. Saves 2 bytes.
2015-12-08 Define macros used for timing delay in uart
    Added a couple of timing delays used by uart.
2015-12-08 Cleanup of macros in uart.
    Balanced macros and also created a function that balances the extra delays needed.
2015-12-08 General uart update.
2015-12-08 36: Move baudrate to configuration file
    Task-Url: http://github.com/dea82/FridgeAlarm/issues/issue/36
    Close #36.
    [conf.h]
2015-12-09 General cleanup of uart
    Cleanup of uart assembler file.
2015-12-11 39: Enable disable uart function
    Task-Url: http://github.com/dea82/FridgeAlarm/issues/issue/39
    Closes #39.
    [main.c]
2015-12-17 Enabled ADC conversion sleep mode. Several power saving improvements.
2015-12-18 Removed unnecessary BOD disable code
    There were some unnecessary (not working) code for BOD disable during sleep. This has now been removed.
    [main.c]
2015-12-25 25: Double AD coversions
    Task-Url: http://github.com/dea82/FridgeAlarm/issues/issue/25
    Fixes #25
    [dsen.c]
2015-12-25 Fix #48: Disable Timer0
    Task-Url: http://github.com/dea82/FridgeAlarm/issues/issue/48
    [main.c]
2015-12-26 Rotated switch.
    [FridgeWarninig_0.5.brd, FridgeWarninig_0.5.sch]
2015-12-28 Major update to finalize project.
    [Case_hall_sensor.skp, FridgeWarninig_0.5.brd, FridgeWarninig_0.5.sch]
2016-04-12 Update comments in uart_asm
2016-04-15 Move maxNumberCycles for cpu load to assembly file
    For better encapsulation the max number of cycles has been moved to assembly file.
2016-04-15 Handle overflow of timer counter for cpu load measurement
    Add a check if an overflow have occured. Then it shall be saturated to 0xFF to indicate this.
2016-04-15 Clear overflow flag before starting timer
    The overflow flag was no cleared before starting the timer for cpu load calculation.
2016-04-19 Minor small fix using macro _BV instead of <<
    [dsen.c]
2016-05-02 Optimization size improvements
    Rewritten som switch to if
2016-05-09 Renamed files for pcb proto board
    [FridgeWarninig_Prototype.brd, FridgeWarninig_Prototype.sch]
2016-05-10 Optimizations in makefile settings
    1. lto - (link time optimization), does not make unnecessary calls to functions in other files. See all files as one single file.
    2. gc-sections - does not link functions that are not called.
    3. nostartfiles - define the interrupt vector self. Does not need to initialize stack pointer etc. New file created boot.S which contains the reset/interrupt vector.
    [conf.h, dsen.c, ledc.c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]
2016-05-10 Add function to indicate low battery
    Red led is light up if a brown-out reset occurs.
    [main.c]
2016-05-10 Turn led orange if unexpected reset occurs
    Also corrected a small bug with CPU load measurement.
    [main.c]
2016-05-11 Corrected bug in sleep
    [main.c]
2016-05-11 Correct bugs after running on target
    Several bugs were identified and corrected when running on target.
    [conf.h, dsen.c, main.c]
2016-05-13 Power consumption fixes and possibility to restart from BOD
    [conf.h, cont.c, dsen.c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]
2016-05-24 Added support for 9600000 clock in buzzer. Buzz is not run when uart is enabled.
    [main.c]
2016-06-01 Make builds targets but must be cleaned between switching targets.
2016-06-15 Added support for generation dependency files for assembly files. Did som cleanup for FLAGS, removed ALL_CFLAGS and ALL_AFLAGS as these were not necessary any more.
2016-06-15 The target is now build in a target specific directory. This solves the problem of switching target without any rebuild of object files. Updated travis file to make it possible to build on CI Travis.
2016-06-15 Makefile - New options added: Debug, cpu load, baud rate
    New possible flags added to Makefile, #60:
    DEBUG_ENABLE: Makes it possible to output something on uart.
    CPU_LOAD: Outputs the actual load of the cpu.
    BAUD_RATE: The actual uart baud rate.
2016-06-15 Don't build attiny13a with CPU_LOAD=1
    Attiny13a does not have a Timer1 which makes it impossible to build attiny13a with flag CPU_LOAD=1 as this uses Timer1.
2016-06-16 Bug fixes after testing on HW
    Several bugs were detected:
    - WDT must be reset immediatly after wakeup. If button interrupt puts the MCU out of sleep, the WDT could have any value and WDT reset can happen at any time.
    - Function in wctc to enable/disable interrupt was not working correctly.
    - Seems that MCU hangs if global interrupt is not enabled before going to ADC Noise reduction mode.
    Implemented compensation for supply loss to hall sensor compared to ADC supply. Fixes #62.
    Still some things to investigate. Reset causes etc.
    [cont.c, dsen.c, main.c]
2016-06-16 Investigation of #57 and #58
    Global interrupt is not enabled automatically bu enabling WDT! Global interrupt must be manually enabled with sei(). Fix #58.
    The clearing of WDT seems to work. Fix #57. However the archtecture for indicating abnormal reset is not good enough. It shold be made as a separate branch not going through all loops again. For example if ADC is taking too long time an WDT reset will occur. When MCU wakes up again it detects this but go through the whole loop again (most likeley new problem with ADC => new reset) it will never come all the way down to powerdown. Find a better solution when investigating creating a tiny scheduler.
    [cont.c, main.c]
2016-06-16 Updated README with avrdude information and fuses
2016-06-16 Trying to create headers for assebly files
    This will make it possible to create Doxygen comments for assembly functions.
2016-06-17 Replaced old error indicator function
    Replaced the old code for putting the MCU to deep sleep with orange led. Now it's not dependent of the normal function loop which could cause it to hang again when an AD conversion takes to long time for example. It's now an independent check and everything is done before entering the main loop.
    [cont.c, ledc.c, main.c]
2016-08-19 Rename dsen to door
    Module handle both sensor read which is transformed to door state which makes door a better module name.
2016-08-28 Updated schematics for "production" version and buzzer proto file
    [FridgeWarninig_Production.brd, FridgeWarninig_Production.sch]
2016-08-30 Code style updates cleanup of schematic
    [FridgeWarninig_Production.sch]
2016-09-14 Fix uart output for cpu load. It now works!
    [conf.h, cont.c, door.c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]
2016-09-17 Draw new case for updated small version of PCB with battery storage
    [assembly.skp]
2016-09-20 Remove macro for adding tasks and replace with function
    Have replaced the macros used for dispatching the tasks and replaced with one function containing #if calls depending if CPU_LOAD is enabled or not. Have made some adjustment of Makefile and enabled warnings for unused parameters.
    [main.c]
2016-09-28 Refactoring macros, inlining and optimization
    Fixes #76.
    Fixes #75.
    Fixes #73.
    [cont.c, door.c, ledc.c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]
2016-09-30 Add baud rate error check
    During a build the actual baud rate error achived is calculated with a shell script and printed.
    Fixes #38.
2016-09-30 Corrected PWM mode for piezo tester program.
    [main.c]
2016-10-01 Fix typo in interrupt table
    Due to a typo in interrupt table Attiny13A did not get a correct interrupt table.
2016-10-01 Add lifecycle calculation (current consumption)
    [FridgeAlarm Current Consumption.xlsx]
2016-10-01 Calibrate buzzer
    Buzzer has been calibrated to 600 Hz and 10% duty cycle.
2016-10-01 Add latest version of CAD models with exported stl
    [assembly.skp, assembly_production.skp, assembly_prototype.skp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]
2016-10-01 Add latest version of PCB drawing
    [FridgeWarninig_Production.brd, FridgeWarninig_Production.sch]
2016-10-01 Updated current consumption estimation
    [FridgeAlarm Current Consumption.xlsx]
2016-11-10 Replace defines with const variables
    Replace defines with const variables for better debugging possibilities
    and type checkning.
    Replace ABS macro with stdlib abs().
    [door.c, ledc.c]
2017-02-21 Remove assembly files
    These are not used and only confuses. Removed them.
2017-02-21 Remove cpu load monitoring script
    This was far from ready not even prototype status. Removed it as Qt application will replace it.
2017-02-22 Do CI with Travis and Docker
    To be able to build consistently with selected versions of tools Docker is used.
    Using a "master" image together with Dockerfile a container containing all build tools necessary is used.
    Most likely Coverity Scan is not working. This can however most likely be fixed at least by attaching Coverity Scan binaries to the image.
2017-03-02 Remove define variables
    Removed define variables and created a new module conf.c which contains all user calibration parameters.
2017-03-03 Remove macro and replace with typesafe functions
    - Removed some macros and replaced them with functions.
    - Removed some experiment code with Hardware Abstraction Layer.
    [cont.c, door.c, ledc.c]

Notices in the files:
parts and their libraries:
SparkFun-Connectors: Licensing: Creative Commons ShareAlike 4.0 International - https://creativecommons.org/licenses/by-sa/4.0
